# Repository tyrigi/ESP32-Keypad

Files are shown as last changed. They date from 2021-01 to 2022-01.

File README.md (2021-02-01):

# ESP32-Keypad

Update: I've started a [Hackaday.io project](https://hackaday.io/project/177226-esp32-bluetooth-gamepad)!

This is a modification to the [Sherbet gaming keypad](https://www.billiam.org/2019/05/29/sherbet-an-ergonomic-keypad) designed by [Billiam](https://www.billiam.org/). The intent is to turn it into a battery-powered bluetooth peripheral. I'm using the ESP32 Arduino libraries, but I'm working in VSCode with [esp-idf](https://github.com/espressif/esp-idf) and [PlatformIO](https://platformio.org/install/ide?install=vscode).

The main reason for not working in the Arduino IDE is the library screwy-ness that is required here. The Sherbet gamepad has an analog stick in addition to regular keyboard inputs, which requires the use of Keyboard HID and Gamepad HID. Both of these options are widely available and pretty easy to implement, but I've been unsuccessful in finding a solution that implements both. Due to how the ESP32-Arduino libraries for both of these options work, the libraries need to be combined into one freakish combination. 

The library I'm using is a combination of the following two libraries:

[ESP32-BLE-Keyboard](https://github.com/T-vK/ESP32-BLE-Keyboard) written by [T-vK](https://github.com/T-vK)

[ESP32-BLE-Gamepad](https://github.com/lemmingDev/ESP32-BLE-Gamepad) written by [lemmingDev](https://github.com/lemmingDev)

I've created a breakout board with an ESP32-WROOM-32E chip that has support for a Li-Ion battery. The Eagle design files, datasheets for critical parts, and a DigiKey BOM have been included for anyone wanting to make one of these for themselves!

Notes:

There have been some issues with my board files. As a disclaimer, older versions of the PCB have pin 32 connected directly to Battery +. I wanted to use the ADC on pin 32 to measure battery voltage, and from there remaining battery capacity. I forgot however that a fully charged Li-Ion battery is 4.2V, which exceeds the ESP32's max input voltage by 0.5V. Not enough to fry the chip, but more than enough to damage the pin. The end effect is that this blasts the UART RX channel in the chip with 4V, rendering the ESP unable to receive new code over the UART interface. So if you're using an old board version, make sure to cut the trace going to I/O pin 32. You've been warned. 

I've since changed this to be fed through a voltage divider to measure the battery. It's constantly draining the battery, but the divider only draws about 9 micro amps, so it shouldn't impact lifespan.

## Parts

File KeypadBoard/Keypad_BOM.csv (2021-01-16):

Manufacturer Part Number | Manufacturer | Digi-Key Part Number | Customer Reference | Reference Designator | Packaging | Part Status | Quantity | Unit Price | Extended Price | Quantity Available | Mfg Std Lead Time | Description | RoHS Status | Lead Free Status | REACH Status
RCS06034K12FKEA | Vishay Dale | 541-RCS06034K12FKEACT-ND |  | R8 | Cut Tape (CT) | Active | 1 | 0.13000 | $0.13 | 4982 | 23 Weeks | RES SMD 4.12K OHM 1% 1/4W 0603 | ROHS3 Compliant | Lead free | Not Available
DMG2305UX-13 | Diodes Incorporated | DMG2305UX-13DICT-ND |  | Q1 | Cut Tape (CT) | Active | 1 | 0.37000 | $0.37 | 783528 | 30 Weeks | MOSFET P-CH 20V 4.2A SOT23 | ROHS3 Compliant | Lead free | REACH Unaffected
SDM2U20SD3-7 | Diodes Incorporated | SDM2U20SD3-7DICT-ND |  | D1 | Cut Tape (CT) | Active | 1 | 0.43000 | $0.43 | 5899 | 15 Weeks | DIODE SCHOTTKY 20V 2A SOD323 | ROHS3 Compliant | Lead free | REACH Unaffected
RQ73C2B143KBTD | TE Connectivity Passive Product | A139919CT-ND |  | R1 | Cut Tape (CT) | Active | 1 | 0.87000 | $0.87 | 9729 | 17 Weeks | RES 143 KOHMS 0.1% 0.4W 1206 | RoHS Compliant | Lead free | Not Available
CL31A476MPHNNNE | Samsung Electro-Mechanics | 1276-3063-1-ND |  | C2 | Cut Tape (CT) | Active | 1 | 0.48000 | $0.48 | 455836 | 22 Weeks | CAP CER 47UF 10V X5R 1206 | ROHS3 Compliant | Lead free | REACH Unaffected
LTC1730ES8-4.2#PBF | Analog Devices Inc. | LTC1730ES8-4.2#PBF-ND |  | U2 | Tube | Active | 1 | 4.66000 | $4.66 | 197 | 8 Weeks | IC BATT CHG LI-ION 1CELL 8SOIC | ROHS3 Compliant | Lead free | REACH Unaffected
MIC37303YME-TR | Microchip Technology | MIC37303YME-CT-ND |  | I1 | Cut Tape (CT) | Active | 1 | 1.57000 | $1.57 | 3487 | 25 Weeks | IC REG LINEAR POS ADJ 3A 8SOIC | ROHS3 Compliant | Lead free | REACH Unaffected
RE1206FRE07100KL | Yageo | 13-RE1206FRE07100KLCT-ND |  | R2, R3 | Cut Tape (CT) | Active | 2 | 0.10000 | $0.20 | 9508 | 24 Weeks | RES SMD 100K OHM 1% 1/4W 1206 | ROHS3 Compliant | Lead free | REACH Unaffected
CGJ3E2X7R1H473K080AA | TDK Corporation | 445-8120-1-ND |  | C4 | Cut Tape (CT) | Not For New Designs | 1 | 0.20000 | $0.20 | 7263 | 28 Weeks | CAP CER 0.047UF 50V X7R 0603 | ROHS3 Compliant | Lead free | REACH Unaffected
LMK107SD223KA-T | Taiyo Yuden | 587-1102-1-ND |  | C3 | Cut Tape (CT) | Active | 1 | 0.32000 | $0.32 | 4088 | 17 Weeks | CAP CER 0.022UF 10V 0603 | ROHS3 Compliant | Lead free | Not Available
060330160104KXT | Knowles Syfer | 1608-1463-1-ND |  | C5 | Cut Tape (CT) | Active | 1 | 1.14000 | $1.14 | 43020 | 8 Weeks | CAP CER | Not Available | Not Available | Not Available
CC0603KPX7R8BB105 | Yageo | 13-CC0603KPX7R8BB105CT-ND |  | C6 | Cut Tape (CT) | Active | 1 | 0.26000 | $0.26 | 56137 | 32 Weeks | MLCC CAP | ROHS3 Compliant | Not Available | REACH Unaffected
CRGH0805F10K | TE Connectivity Passive Product | A126417CT-ND |  | R5 | Cut Tape (CT) | Active | 1 | 0.10000 | $0.10 | 71258 | 18 Weeks | RES SMD 10K OHM 1% 1/3W 0805 | RoHS Compliant | Lead free | Not Available
CRGS0603J4R7 | TE Connectivity AMP Connectors | A129230CT-ND |  | R6 | Cut Tape (CT) | Active | 1 | 0.35000 | $0.35 | 6040 | 18 Weeks | RES SMD 4.7 OHM 5% 1/4W 0603 | RoHS Compliant | Lead free | Not Available
ERJ-3BWJR050V | Panasonic Electronic Components | P17490CT-ND |  | R9 | Cut Tape (CT) | Active | 1 | 0.42000 | $0.42 | 8218 | 22 Weeks | RES 0.05 OHM 5% 1/3W 0603 | ROHS3 Compliant | Lead free | Not Available
CRGH0805J1K0 | TE Connectivity Passive Product | A126435CT-ND |  | R4, R7, R10, R11 | Cut Tape (CT) | Active | 4 | 0.10000 | $0.40 | 35103 | 18 Weeks | RES SMD 1K OHM 5% 1/3W 0805 | RoHS Compliant | Lead free | Not Available
ESP32-WROOM-32E (4MB) | Espressif Systems | 1965-ESP32-WROOM-32E(4MB)CT-ND |  | U1 | Cut Tape (CT) | Active | 1 | 2.50000 | $2.50 | 9833 | 8 Weeks | RX TXRX MOD WIFI TRACE ANT SMD | Not Available | Not Available | Not Available
CGA5L2X7R2A105K160AE | TDK Corporation | 445-8801-1-ND |  | C1 | Cut Tape (CT) | Active | 1 | 0.85000 | $0.85 | 31785 | 12 Weeks | CAP CER 1UF 100V X7R 1206 | ROHS3 Compliant | Lead free | REACH Unaffected

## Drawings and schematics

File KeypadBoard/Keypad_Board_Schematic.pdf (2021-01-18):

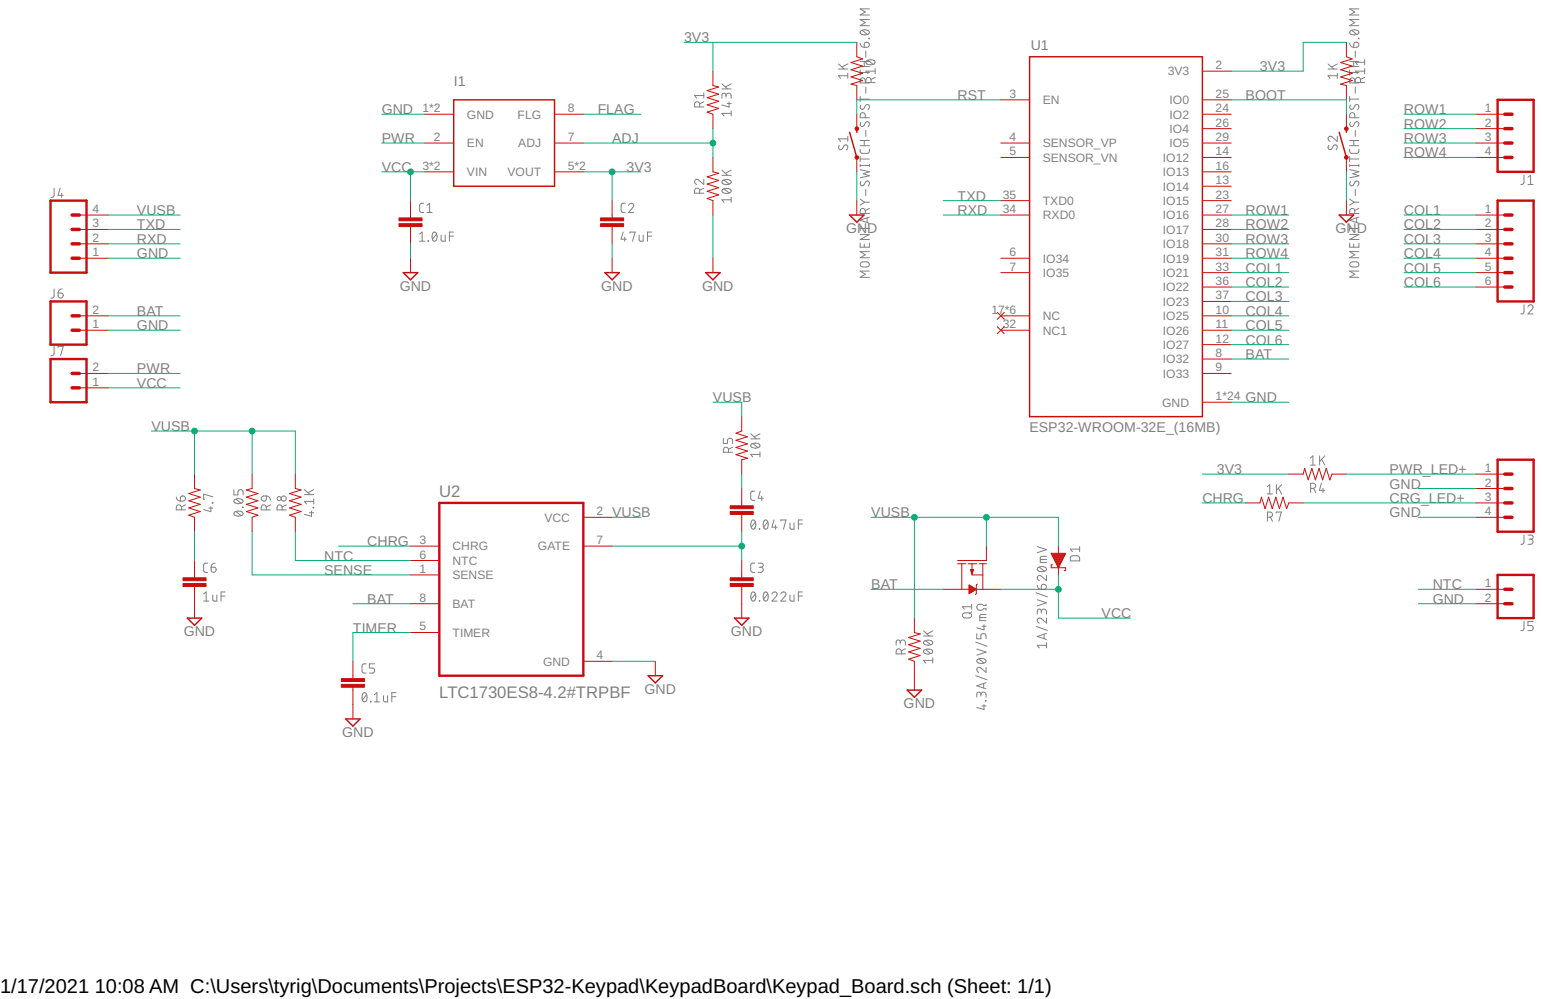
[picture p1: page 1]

1/17/2021 10:08 AM C:\Users\tyrig\Documents\Projects\ESP32-Keypad\KeypadBoard\Keypad_Board.sch (Sheet: 1/1)

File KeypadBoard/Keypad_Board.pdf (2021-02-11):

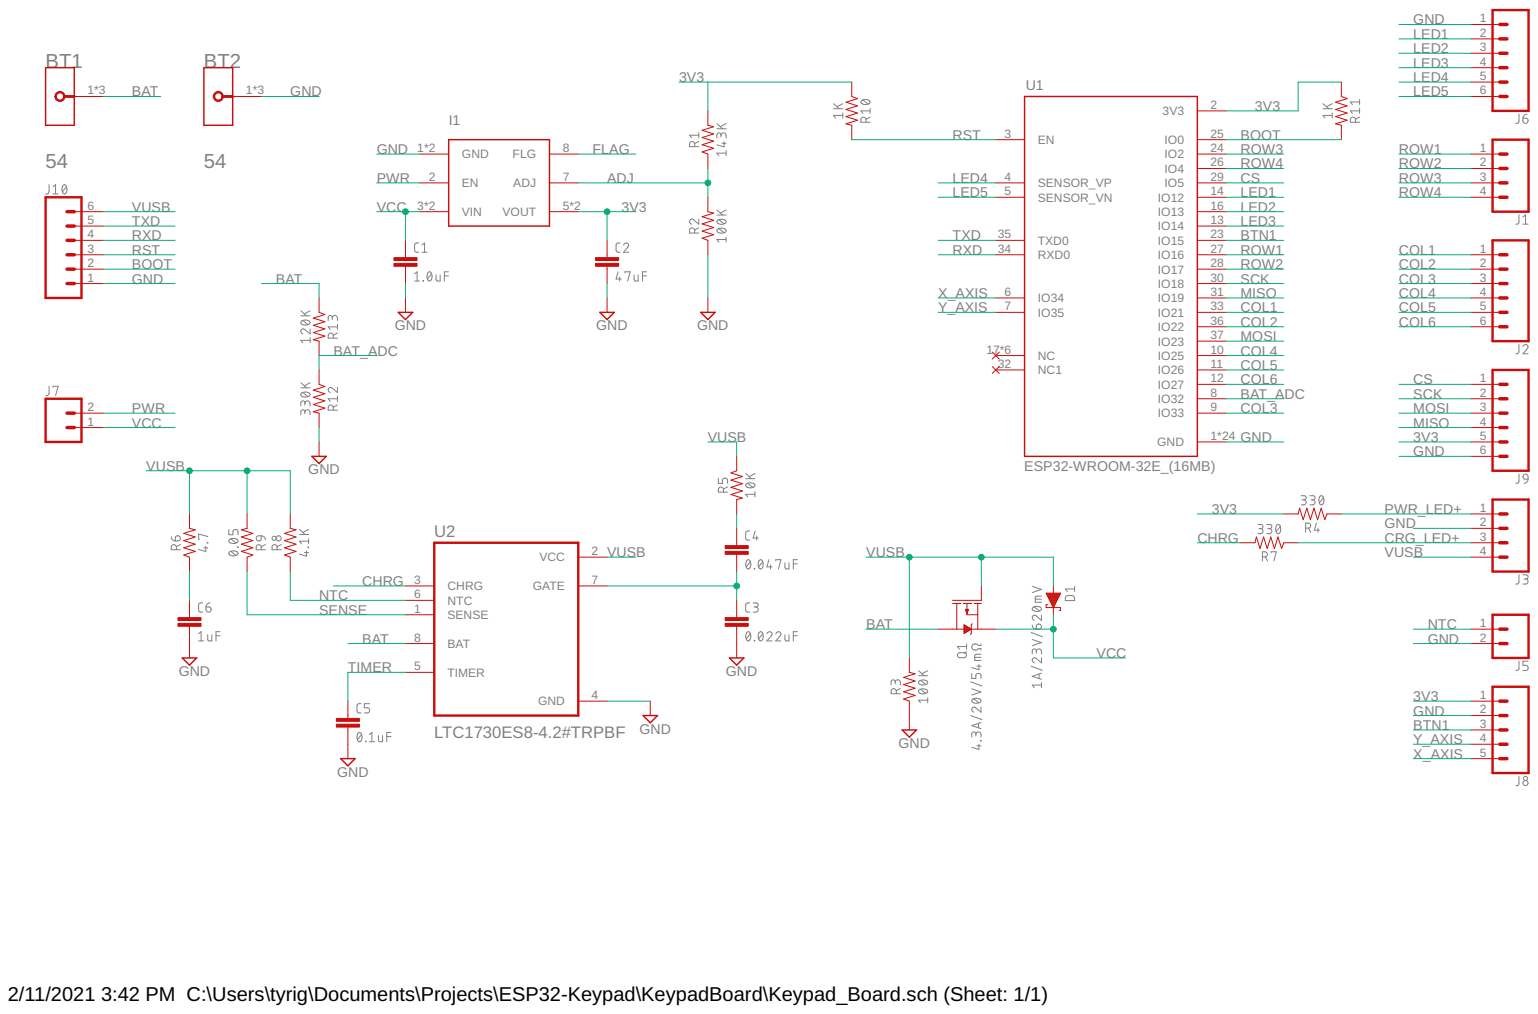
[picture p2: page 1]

2/11/2021 3:42 PM C:\Users\tyrig\Documents\Projects\ESP32-Keypad\KeypadBoard\Keypad_Board.sch (Sheet: 1/1)

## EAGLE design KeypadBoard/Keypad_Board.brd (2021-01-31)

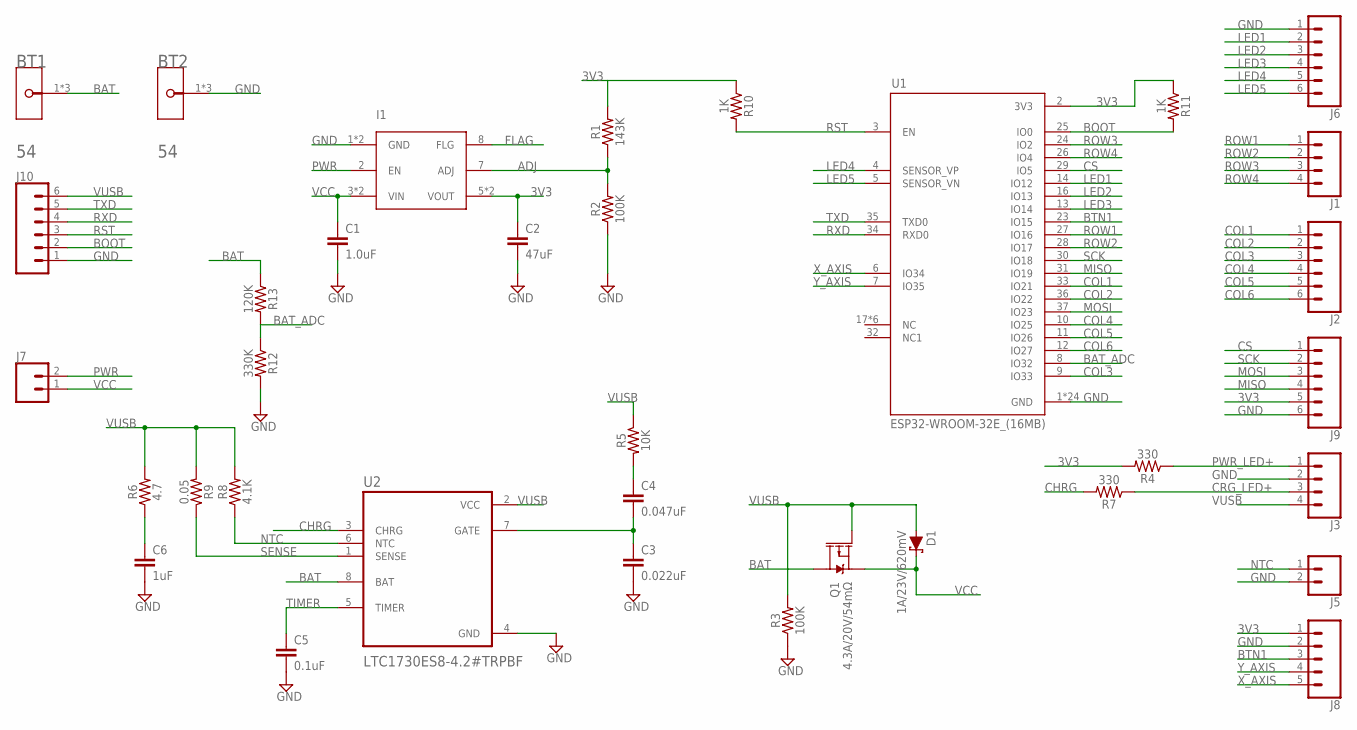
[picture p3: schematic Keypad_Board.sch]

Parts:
BT1, BT2: KEYSTONE_54KEYSTONE_54_0_0; KEYSTONE_54_0
C1: 1.0uF; 1206
C2: 47uF; 1206
C3: 0.022uF; 0603
C4: 0.047uF; 0603
C5: 0.1uF; 0603
C6: 1uF; 0603
D1: 1A/23V/620mV; SOD-323
I1: MIC37303; SOIC8
J1, J3: CONN_04; 1X04
J2, J6, J9, J10: CONN_06LOCK; 1X06_LOCK
J5, J7: CONN_02; 1X02
J8: CONN_05; 1X05
Q1: 4.3A/20V/54mΩ; SOT23-3
R1: 143K; 1206
R2, R3: 100K; 1206
R4, R7: 330; 0805
R5: 10K; 0805
R6: 4.7; 0603
R8: 4.1K; 0603
R9: 0.05; 0603
R10, R11: 1K; 0805
R12: 330K; 0805
R13: 120K; 0805
U1: ESP32-WROOM-32E_(16MB); MODULE_ESP32-WROOM-32E_(16MB)
U2: LTC1730ES8-4.2#TRPBF; SO-8_S

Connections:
3V3: C2.1, I1.5 (VOUT), I1.6 (VOUT), J8.1, J9.5, R1.2, R4.2, R10.1, R11.1, U1.2 (3V3)
ADJ: I1.7 (ADJ), R1.1, R2.2
BAT: BT1.1, BT1.1-2, BT1.1-3, Q1.3 (D), R13.1, U2.8 (BAT)
BAT_ADC: R12.1, R13.2, U1.8 (IO32)
BOOT: J10.2, R11.2, U1.25 (IO0)
BTN1: J8.3, U1.23 (IO15)
CHRG: R7.2, U2.3 (CHRG)
COL1: J2.1, U1.33 (IO21)
COL2: J2.2, U1.36 (IO22)
COL3: J2.3, U1.9 (IO33)
COL4: J2.4, U1.10 (IO25)
COL5: J2.5, U1.11 (IO26)
COL6: J2.6, U1.12 (IO27)
CRG_LED+: J3.3, R7.1
CS: J9.1, U1.29 (IO5)
FLAG: I1.8 (FLG)
GND: BT2.1, BT2.1-2, BT2.1-3, C1.2, C2.2, C3.2, C5.2, C6.2, I1.1 (GND), I1.9 (GND), J3.2, J5.2, J6.1, J8.2, J9.6, J10.1, R2.1, R3.1, R12.2, U1.1 (GND), U1.15 (GND), U1.38 (GND), U1.39_1 (GND), U1.39_2 (GND), U1.39_3 (GND), U1.39_4 (GND), U1.39_5 (GND), U1.39_6 (GND), U1.39_7 (GND), U1.39_8 (GND), U1.39_9 (GND), U1.39_10 (GND), U1.39_11 (GND), U1.39_12 (GND), U1.39_13 (GND), U1.39_14 (GND), U1.39_15 (GND), U1.39_16 (GND), U1.39_17 (GND), U1.39_18 (GND), U1.39_19 (GND), U1.39_20 (GND), U1.39_21 (GND), U2.4 (GND)
LED1: J6.2, U1.14 (IO12)
LED2: J6.3, U1.16 (IO13)
LED3: J6.4, U1.13 (IO14)
LED4: J6.5, U1.4 (SENSOR_VP)
LED5: J6.6, U1.5 (SENSOR_VN)
MISO: J9.4, U1.31 (IO19)
MOSI: J9.3, U1.37 (IO23)
unnamed: C4.1, R5.2
unnamed: C3.1, C4.2, U2.7 (GATE)
unnamed: C6.1, R6.1
NTC: J5.1, R8.1, U2.6 (NTC)
PWR: I1.2 (EN), J7.2
PWR_LED+: J3.1, R4.1
ROW1: J1.1, U1.27 (IO16)
ROW2: J1.2, U1.28 (IO17)
ROW3: J1.3, U1.24 (IO2)
ROW4: J1.4, U1.26 (IO4)
RST: J10.3, R10.2, U1.3 (EN)
RXD: J10.4, U1.34 (RXD0)
SCK: J9.2, U1.30 (IO18)
SENSE: R9.1, U2.1 (SENSE)
TIMER: C5.1, U2.5 (TIMER)
TXD: J10.5, U1.35 (TXD0)
VCC: C1.1, D1.C, I1.3 (VIN), I1.4 (VIN), J7.1, Q1.2 (S)
VUSB: D1.A, J3.4, J10.6, Q1.1 (G), R3.2, R5.1, R6.2, R8.2, R9.2, U2.2 (VCC)
X_AXIS: J8.5, U1.6 (IO34)
Y_AXIS: J8.4, U1.7 (IO35)

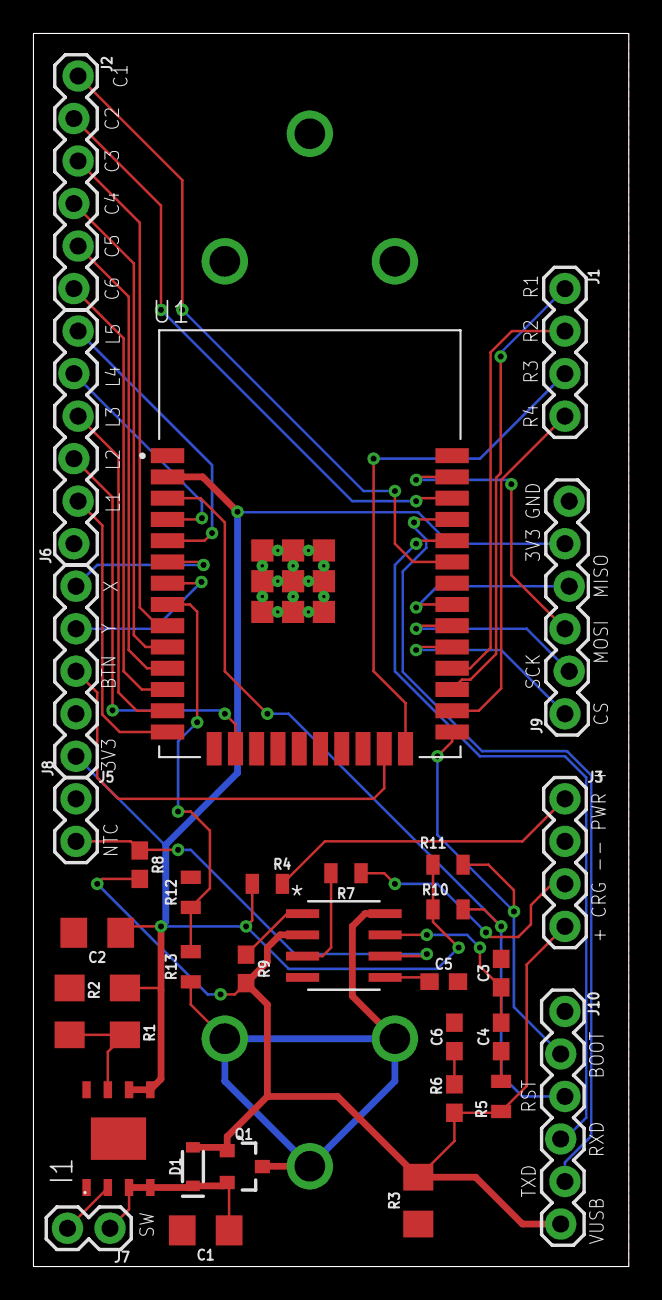
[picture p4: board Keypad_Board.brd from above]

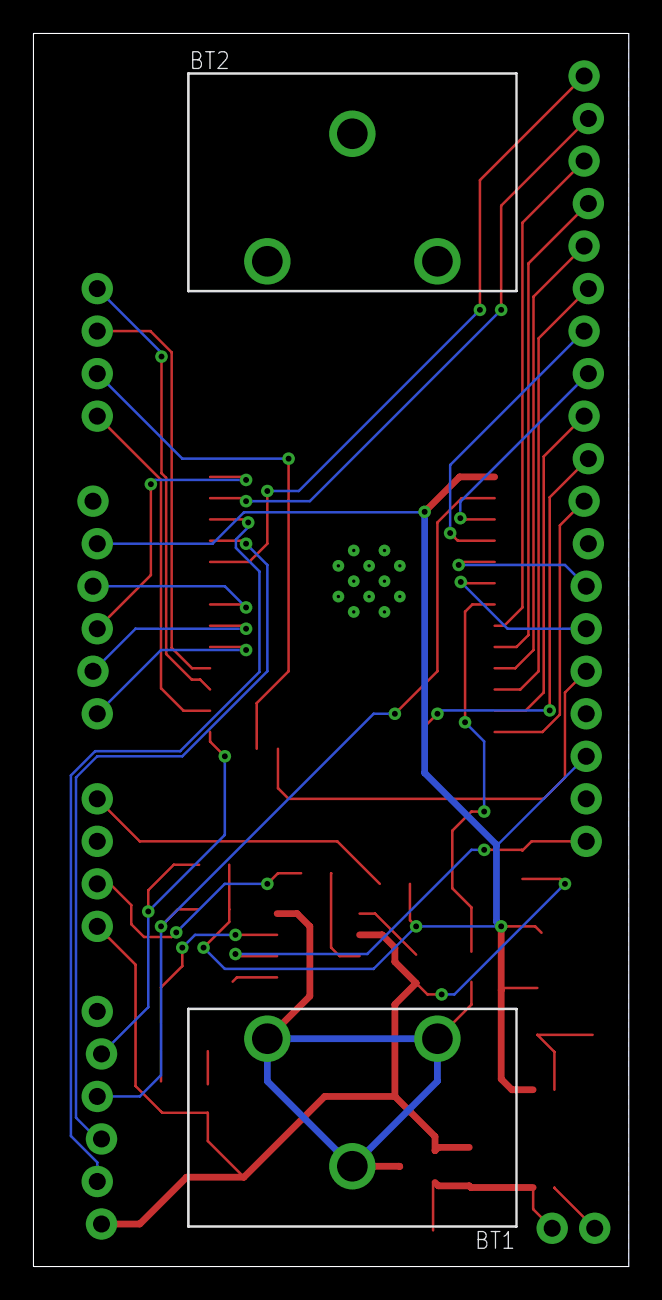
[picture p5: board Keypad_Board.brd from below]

Board: 2 copper layers, 35.6 x 73.7 mm, 35 parts (2 on the bottom side), 43 nets.

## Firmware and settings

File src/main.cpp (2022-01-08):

/* 
 * This is the master code for the ESP32 Wireless Sherbet Keypad, based on Billiam's
 * design (https://www.billiam.org/).
 * 
 * ToDo:
 *  - Add a timeout to deep sleep after a period of inactivity for additional power savings
 *  - Implement user-definable layouts imported from a JSON file on an attached SD card.
 *  - Implement a fallback layout to use when an SD card is not found or JSON file is corrupted.
 *  - Implement a different mode-switching function for keycombo detetection
 *  - Implement a key-press joystick mode for software that doesn't support joystick input.
 */

#include <Arduino.h>
#include "BleSherbet.h"
#include "Bounce2.h"

//#include "FS.h"
#include "SD.h"
#include <SPI.h>

//Abstracting out whether a key has been pressed or released
#define PRESSED(row, col) switches[row][col].fell()
#define RELEASED(row, col) switches[row][col].rose()

#define ISIN(CH, ARRY) std::find(std::begin(ARRY), std::end(ARRY), CH) != std::end(ARRY)
#define GETPOS(CH, ARRY) std::find(std::begin(ARRY), std::end(ARRY), CH)

//General info about the physical keypad
const int ROW_COUNT = 4; 							//Number of rows
const int COL_COUNT = 6; 							//Number of columns
const int BTN_COUNT = 1; 							//Number of buttons (for joystick stuff)
const int MODE_COUNT = 3; 							//Number of total Layouts - will be removed when layouts defined on SD Card
const int JOY_X_PIN = 35; 							//Joystick X Axis
const int JOY_Y_PIN = 34; 							//Joystick Y Axis
const int BAT_PIN = 32; 							//Battery level measurement 
const int rowPins[] = {4, 2, 17, 16};				//Row GPIO's
const int colPins[] = {21, 22, 33, 25, 26, 27}; 	//Column GPIO's
const int buttonPins[] = {15}; 						//Joystick button GPIO's
const int modePins[] = {2, 4, 5}; 					//Mode control buttons (carryover from teensy)
const int ledPins[] = {12, 13, 14}; 				//LED indicator pins (carryover from teensy)

//Descriptions of the scanning process
const int DEBOUNCE = 3; 							//Debounce period for button debouncing
const int SCAN_DELAY = 20; 							//Delay between scan cycles
static bool update = false;							//Indicator - cycle has registered a valid change that requires an update
const int COL_STATE = HIGH;							//State the column should be in when not being read
const int COL_MODE = OUTPUT;						//Mode that the column pins should be put in during setup
const int ROW_MODE = INPUT_PULLUP;					//Mode to initialize the rows to during startup

//Joystick information
const bool REV_X = true;							//Invert X Axis
const bool REV_Y = true;							//Invert Y Axis
const int MIN_ADC = 0;								//Minimum ADC reading for scaling output
const int MAX_ADC = 4096;							//Maximum ADC reading for scaling output
static int MIN_X = 400;								//Minimum typical X Axis ADC reading
static int MAX_X = 2800;							//Maximum typical X Axis ADC reading
static int MIN_Y = 400;								//Minimum typical Y Axis ADC reading
static int MAX_Y = 2800;							//Maximum typical Y Axis ADC reading
const int JOY_MIN = -32767;							//Minimum reportable Axis Value
const int JOY_MAX = 32767;							//Maximum reportable Axis Value
static float JOY_DEVIATION = 0.03;					//Minimum deviation from previous value before update
static int prev_x = 0;								//Previous X Axis reading
static int prev_y = 0;								//Previous Y Axis reading
int x_read = 0;										//Current cycle's X Axis ADC reading
int y_read = 0;										//Current cycle's Y Axis ADC reading
int axes_current[] = {512, 512};					//Current scaled Axis readings
int axes_prev[] = {0,0};							//Previous cycle's scaled Axis readings

//Battery measurement information
const int BAT_MAX = 3960;							//ADC value at maximum voltage (Battery @4.2V)
const int BAT_MIN = 2925;							//ADC value at minimum voltage (Battery @3.0V)
const int LEVEL_SAMPLES = 128;						//Number of samples to average over
static int BAT_LEVEL = 100;							//Battery level as percentage scaled from 4.2V to 3.0V (linear)
static int PREV_LEVEL = 0;							//Previous battery level reading
static int AVG_BAT_LEVEL = 0;						//Averaged battery level reading
static int BAT_ADC = 3960;							//Read ADC value (used for averaging)
static int MEASURE_COUNT = 0;						//Counted number of samples

//SD Card Stuff
#define SD_CS 5
static bool CARD_AVAILABLE = false;
const char LETTERS[] = {'a', 'b', 'c', 'd', 'e', 'f', 'g', 'h', 'i', 'j',
							'k', 'l', 'm', 'n', 'o', 'p', 'q', 'r', 's', 't', 
							'u', 'v', 'w', 'x', 'y', 'z', 'A', 'B', 'C', 'D', 
							'E', 'F', 'G', 'H', 'I', 'J', 'K', 'L', 'M', 'N', 
							'O', 'P', 'Q', 'R', 'S', 'T', 'U', 'V', 'W', 'X', 
							'Y', 'Z'}; 
const char NUMBERS[] = {'0', '1', '2', '3', '4', '5', '6', 
							'7', '8', '9'};
const char SYMBOLS[] = {'_'};
const char COMMA[] = {','};

//Object instances
Bounce btnDebounce[BTN_COUNT];						//Joystic button debounce objects
Bounce switches[ROW_COUNT][COL_COUNT];				//Keypad key debounce objects
Bounce modeDebounce[MODE_COUNT];					//Mode button debounce objects

BleKeypad bleKeypad;								//The keypad object


//Temporary layout management variables
int keyLayer = 0;
const int totalKeyLayers = 3;
const int keyMap[totalKeyLayers][ROW_COUNT][COL_COUNT] = {
{
	{KEY_ESC, KEY_O, KEY_I, KEY_Q, KEY_V, KEY_T},
	{KEY_P, KEY_J, KEY_X, KEY_LEFT_ALT, KEY_E, KEY_R},
	{KEY_L, KEY_LEFT_CTRL, KEY_TAB, KEY_LEFT_SHIFT, KEY_SPACE, KEY_F},
	{KEY_K, KEY_S, KEY_W, KEY_C, KEY_Z, KEY_M}
},
{
	{BUTTON_1,BUTTON_2,BUTTON_3,BUTTON_4,BUTTON_5,BUTTON_6},
	{BUTTON_7,BUTTON_8,BUTTON_9,BUTTON_10,BUTTON_11,BUTTON_12},
	{BUTTON_13,BUTTON_14,BUTTON_15,BUTTON_16,BUTTON_17,BUTTON_18},
	{BUTTON_19,BUTTON_20,BUTTON_21,BUTTON_22,BUTTON_23,BUTTON_24}
},
{
	{KEY_ESC, KEY_1, KEY_2, KEY_3, KEY_4, KEY_M},
	{KEY_0, KEY_TAB, KEY_O, KEY_X, KEY_E, KEY_R},
	{KEY_9, KEY_LEFT_ALT, KEY_LEFT_CTRL, KEY_LEFT_SHIFT, KEY_SPACE, KEY_F},
	{KEY_8, KEY_V, KEY_Z, KEY_C, KEY_Q, KEY_B}
}
};

const int MAX_LAYERS = 5;
static String layout[MAX_LAYERS][ROW_COUNT][COL_COUNT];

/*
Determines whether a given character is a valid character for a key encoding.
*/
//bool charIsValid(char ch){
//	bool exists = std::find(std::begin(VALID_CHARS), std::end(VALID_CHARS), ch) != std::end(VALID_CHARS);
//	return exists;
//}


/*
Scan through all rows of a given column for state changes.
*/
void rowScan(int col) {
	for (int row = 0; row < ROW_COUNT; row++){
		switches[row][col].update();
	}

	for (int row = 0; row < ROW_COUNT; row++){
		if (PRESSED(row, col)){
			Serial.print(row, DEC);
			Serial.print(":");
			Serial.print(col, DEC);
			Serial.print(" Pressed\n");
			if (keyLayer != 1){
				bleKeypad.presskey(keyMap[keyLayer][row][col]);
			} else if (keyLayer == 1){
				bleKeypad.press(keyMap[keyLayer][row][col]);
			}
			Serial.print(keyMap[keyLayer][row][col]);
			Serial.print(" Pressed\n");
			update = true;
			return;
			//press the button of the right layer
		} else if (RELEASED(row, col)){
			Serial.print(row, DEC);
			Serial.print(":");
			Serial.print(col, DEC);
			Serial.print(" Released\n");
			if (keyLayer != 1){
				bleKeypad.releasekey(keyMap[keyLayer][row][col]);
			} else if (keyLayer == 1){
				bleKeypad.release(keyMap[keyLayer][row][col]);
			}
			Serial.print(keyMap[keyLayer][row][col]);
			Serial.print(" Released\n");
			update = true;
			return;
			//release the button of the right layer
		}
	}
}

/*
Scan the key matrix for changes in key status. The row pins are have
alread been set as inputs with a weak pullup, so now the columns are 
set to a logic LOW state. When a button in the currently LOW column is 
pressed, the cooresponding row pin detects a change from HIGH to LOW.
When the switch is released, the opposite is true. 

We're only interested in changes in key state (unpressed -> pressed or 
pressed -> unpressed), so we only look for rising or falling edges. When
one is detected, the key code from the layout matrix cooresponding to the
correct row and column is transmitted to the computer.

The update variable is only set true when a key press or a key release
event is logged.
*/
void keyScanner() {
	for (int col = 0; col < COL_COUNT; col++){
		//Set the current column to GND state
		digitalWrite(colPins[col], !COL_STATE);

		//Flip row pins high and low really fast to dump any charge
		//accumulation due to internal bootstrapping pin hardware.
		for (int row = 0; row < ROW_COUNT; row++){
			pinMode(rowPins[row], OUTPUT);
			digitalWrite(rowPins[row], LOW);
			digitalWrite(rowPins[row], HIGH);
			pinMode(rowPins[row], INPUT_PULLUP);
		}

		//Scan all buttons in the column for changes
		rowScan(col);
		
		//Switch off the current column to a HIGH logic state 
		digitalWrite(colPins[col], COL_STATE);
	}
}

/*
The mapping of joystick values to adc values is sensitive to the range
reported by the adc. Essentially, if the read ADC value is outside the 
min/max range specified in the MAX_ and MIN_ variables, the output will 
wrap around. To maintain sensitivity, we want these bounds to be as 
closely mapped to what is reported as possible. 

Easy fix is to keep the bounds slightly elastic. If the read value goes 
out of bounds, move the bounds. This makes the joystic sensitive to 
drift, but since values don't drift very much in this particular setup, 
it doesn't cause too many problems.
*/
void joyRunCal(int adcX, int adcY){
	if (adcX > MAX_X){
		MAX_X = adcX;
	}
	if (adcX < MIN_X){
		MIN_X = adcX;
	}
	if (adcY > MAX_Y){
		MAX_Y = adcY;
	}
	if (adcY < MIN_Y){
		MIN_Y = adcY;
	}
}


/*
This function scans the Joystick for changes. We read the voltage
at the X axis and Y axis, which gives a value from 0 to 4096. This
value is then re-mapped to the joystick outputs of -32767 to 32767.

To save power by supressing unnecessary updates, the X and Y values
of the Joystick are only updated if the value changes by a certain
percentage from the previous reading. This percentage is set by 
JOY_DEVIATION.
*/
void joyScanner(){
	//Read in the values. We'll be doing some massaging of these values, so we want them static.
	x_read = analogRead(JOY_X_PIN);
	y_read = analogRead(JOY_Y_PIN);
	joyRunCal(x_read, y_read);

	//Compare the current readings to the previous readings. If the readings differ by more
	//than a specified percentage, the new value will be sent over to the paired device.
	float tempX = (float)abs(x_read - prev_x) / (float)prev_x;
	float tempY = (float)abs(y_read - prev_y) / (float)prev_y;

	//If the joystic output has changed sufficiently, map output values and prepare an update
	if (tempX > JOY_DEVIATION || tempY > JOY_DEVIATION){
		//Map X axis ADC reading to joystick output values
		if (!REV_X){
			axes_current[0] = map(constrain(x_read, MIN_ADC, MAX_ADC), MIN_X, MAX_X, JOY_MIN, JOY_MAX);
		} else {
			//Reversed X axis
			axes_current[0] = map(constrain(x_read, MIN_ADC, MAX_ADC), MIN_X, MAX_X, JOY_MAX, JOY_MIN);
		}

		//Map Y axis ADC reading to joystick output values
		if (!REV_Y){
			axes_current[1] = map(constrain(y_read, MIN_ADC, MAX_ADC), MIN_Y, MAX_Y, JOY_MIN, JOY_MAX);
		} else {
			//Reversed y axis
			axes_current[1] = map(constrain(y_read, MIN_ADC, MAX_ADC), MIN_Y, MAX_Y, JOY_MAX, JOY_MIN);
		}

		//Use the current ADC values for next cycle's comparison
		//Only updating these if the value is updated prevents very slow,
		//small movements of the joystick being ignored as the per-cycle
		//change could cause the reference point to drift without triggering
		//an update.
		prev_x = x_read;
		prev_y = y_read;

		//Queue an update
		bleKeypad.setX(axes_current[0]);
		bleKeypad.setY(axes_current[1]);
		//Construct the packet to be sent as an update
		bleKeypad.sendReport();

		//Indicate that a change worthy of an update has occured
		update = true;
	}
}


/*
This function checks for a button press to switch between
layouts. The only 'button' I've set up on this keypad is
the Joystick push button (when you press on the stick). 

No update needs to be logged for this event since the 
computer doesn't need to be informed of layout changes.
*/
void modeScanner(){
	btnDebounce[0].update();
	if (btnDebounce[0].fell()){
		keyLayer++;
		Serial.print("Mode updated to ");
		Serial.print(keyLayer);
		Serial.print("\n");
	}
	if (keyLayer == totalKeyLayers){
		keyLayer = 0;
		Serial.print("Mode updated to ");
		Serial.print(keyLayer);
		Serial.print("\n");
	}
}


/*
This function reads the voltage level of the battery,
then scales it relative to the minimum and maximum 
battery voltages for reporting a percentage. The
keypad uses a single Li-Ion cell, which has a max 
voltage of 4.2V (when fully charged). I've set the
minimum to 3.0V to keep the battery from being fully
discharged. This will impact battery lifespan a bit,
but it should make the battery last longer before
needing to be replaced.

To save on unnecessary updates (which saves power), 
an update is only logged if the battery percentage
changes by 5%. And only increments of 5% are logged,
since the voltage reading can fluctuate by 1-2%.
*/
void updateBatLevel(){
	MEASURE_COUNT++;
	BAT_ADC = analogRead(BAT_PIN);
	BAT_LEVEL = map(constrain(BAT_ADC, BAT_MIN, BAT_MAX), BAT_MIN, BAT_MAX, 0, 100);
	AVG_BAT_LEVEL += BAT_LEVEL;
	if (MEASURE_COUNT == LEVEL_SAMPLES){
		AVG_BAT_LEVEL = AVG_BAT_LEVEL/LEVEL_SAMPLES;
		AVG_BAT_LEVEL = (AVG_BAT_LEVEL/5)*5;
		if (AVG_BAT_LEVEL != PREV_LEVEL){
			PREV_LEVEL = AVG_BAT_LEVEL;
			bleKeypad.setBatteryLevel(AVG_BAT_LEVEL);
			update = true;
		}
		MEASURE_COUNT = 0;
		AVG_BAT_LEVEL = 0;
	}
}

void readUntil(File* file, String& str, char* delim){
	
}

String * parseLine(String& str){
	
}

void parseLayout(File* file){
	
}


/*
Set up the hardware and instantiate all necessary objects/variables.
*/
void setup() {
  	//Configure Serial port for debug messages
	Serial.begin(115200);
  	bleKeypad.begin();

//Initialize and read SD Card
/*
	pinMode(SD_CS, OUTPUT);
	digitalWrite(SD_CS, HIGH);
	pinMode(23, INPUT_PULLUP);
	CARD_AVAILABLE = SD.begin(SD_CS);
	if (CARD_AVAILABLE){
		Serial.println("SD Card Found!");
		uint8_t cardType = SD.cardType();
		if(cardType == CARD_NONE){
			CARD_AVAILABLE = false;
			Serial.println("ERROR -- No SD Card present.");
		}else{
			Serial.println("Initializing SD Card");
			File file = SD.open("/data.txt");
			file.seek(0);
			if (!file){
				Serial.println("ERROR -- File not found.");
			}else{
				Serial.println("Reading from file...");
				parseLayout(&file);
				Serial.println("Done reading from file.");
				
				file.close();
			}
		}
	}
*/
//Start by configuring GPIO:
	
	//Set rows to initial state
	for (int row=0; row<ROW_COUNT; row++){
		pinMode(rowPins[row], ROW_MODE);
	}
	//Set columns to initial state
	for (int col=0; col<COL_COUNT; col++){
		pinMode(colPins[col], COL_MODE);
		digitalWrite(colPins[col], COL_STATE);
	}
	//Set button to initial state
	pinMode(buttonPins[0], INPUT_PULLUP);

	//Initially, this was a for loop, but we only have one button
	Bounce debouncer = Bounce();
	debouncer.attach(buttonPins[0], INPUT_PULLUP);
	debouncer.interval(DEBOUNCE);
	btnDebounce[0] = debouncer; //Doesn't need to be an array, legacy carryover
	//Set up Joystick



	//Create and associate debounce objects





	//for (int row = 0; row < ROW_COUNT; row++){
	//	pinMode(rowPins[row], INPUT_PULLUP);
	//}
	
	//Set all columns to INPUT (high-impedance)
	//for (int col = 0; col < COL_COUNT; col++){
	//	//pinMode(colPins[col], INPUT);
	//	pinMode(colPins[col], OUTPUT);
	//	digitalWrite(colPins[col], HIGH);
	//}
	
	//Create one debounce object per key
	for (int row = 0; row < ROW_COUNT; row++){
		for (int col = 0; col < COL_COUNT; col++){
			Bounce debouncer = Bounce();
			debouncer.attach(rowPins[row], INPUT_PULLUP);
			debouncer.interval(DEBOUNCE);
			switches[row][col] = debouncer;
		}
	}
	
	//Create debounce objects for extra buttons
	for (int btn = 0; btn < BTN_COUNT; btn++){
		Bounce debouncer = Bounce();
		debouncer.attach(buttonPins[btn], INPUT_PULLUP);
		debouncer.interval(DEBOUNCE);
		btnDebounce[btn] = debouncer;
	}
	
	//Create debounce objects for mode buttons
	for (int mode = 0; mode < MODE_COUNT; mode++){
		Bounce debouncer = Bounce();
		debouncer.attach(modePins[mode], INPUT);
		debouncer.interval(DEBOUNCE);
		modeDebounce[mode] = debouncer;
	}
	//Serial.print("Setup complete\n");
}

void loop() {
	//Don't bother doing anything if we're not connected to anything.
  	if(bleKeypad.isConnected()) {
		//Check for a layer change
      	modeScanner();
		//Check for keypresses
	  	keyScanner();
		//Check for joystick movement
	  	joyScanner();
		//Check for a change in battery level
	  	updateBatLevel();
		//If any changes have been logged, send an update
	  	if (update==true){
		  	bleKeypad.sendUpdate();
		  	update = false;
		}
		//No need to free-wheel, that just uses unnecessary power.
	  	delay(SCAN_DELAY);
  	}
}

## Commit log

2021-01-15 Adding board design progress and datasheets for critical components
    [Keypad_Board.sch]
2021-01-15 First draft of board layout
    [Keypad_Board.brd]
2021-01-16 Completed board layout, Rev 1
2021-01-16 Added DigiKey BOM that can be imported into DigiKey
    [Keypad_BOM.csv]
2021-01-18 Switched from XInput to HID Gamepad, integration builds but doesn't work yet
    [main.cpp]
2021-01-20 Board Rev2
    [Keypad_Board.brd, Keypad_Board.sch]
2021-01-26 Board updates - ADC OverVoltage fix
    [Keypad_Board.brd, Keypad_Board.sch]
2021-01-29 Joystick constantly re-calibrates to avoid weird drift
    [main.cpp]
2021-01-29 Update README.md
    Added board defect warning
2021-01-30 Added battery level monitoring and charge LED
    [Keypad_Board.brd, Keypad_Board.sch]
2021-01-30 Updated board for connection of a Micro SD Card module
    [Keypad_Board.brd, Keypad_Board.sch]
2021-01-31 Removed debugging lines, added comments, and reduced power draw
2021-01-31 Board V4 - integrated battery holder, SD Breakout, mode LED's
    [Keypad_Board.brd, Keypad_Board.sch]
2021-02-11 Updated schematic pdf

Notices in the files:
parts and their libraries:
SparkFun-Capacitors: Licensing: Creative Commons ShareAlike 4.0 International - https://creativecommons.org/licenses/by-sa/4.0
